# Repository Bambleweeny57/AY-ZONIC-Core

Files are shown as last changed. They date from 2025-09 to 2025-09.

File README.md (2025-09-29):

# 🔊AY-ZONIC-Core

AY-ZONIC-Core is a modular PSG interface designed for the ZX81, supporting both ZON-X and ZON-X-81 compatibility via simplified A4-only decode logic. Rev2.0 introduces gate economy, contributor-friendly schematic clarity, and expansion-ready I/O via AY-3-8912 Port A.

> **This project continues from [JonZON-X](https://github.com/Bambleweeny57/JonZON-X), which was closed at Rev1.4** after timing issues were discovered in demo playback. AY-ZONIC-Core retains the same A4-based decode logic but drops A5 and A6 simplifying the design to single PSG support and saving a gate.

## 🔧 Features

- **Dual-mode decode logic** via DIP switch:
  - **DIP OFF** → A4 pulled high → ZON-X-81 mode
  - **DIP ON** → A4 sourced from ZX81 Expansion Bus → ZON-X mode
- **AY-3-8912 PSG integration** with clean register selection and audio output
- **Series resistors** on data bus for signal protection
- **Pull-ups** from ZX81 Expansion Bus to PSG for stable logic levels
- **Port A expansion header** with +5V and GND for SD card and I/O experimentation
- **/RD decode support** for future peripheral interaction and PSG reads
### DIP Switch Logic — A4 Routing Modes

| DIP Switch | A4 Source | Mode | Description |
|---|---|---|---|
| OFF | Pulled high (via pull-up) | ZON-X-81 | Forces A4 = 1 for simplified decode |
| ON | From ZX81 Expansion Bus  | ZON-X | Enables dynamic A4 control from host |

> This DIP-controlled logic allows seamless switching between ZON-X and ZON-X-81 compatibility without modifying the schematic.
> 
## 🧠 Decode Logic Overview

The schematic uses simplified A4-only address decoding, inherited from JonZON-X Rev1.4. By removing A5 and A6 from the decode path, Rev2.0 drops multi-PSG support in favor of gate economy and contributor clarity.

## 🖼️ Visual Decode Logic

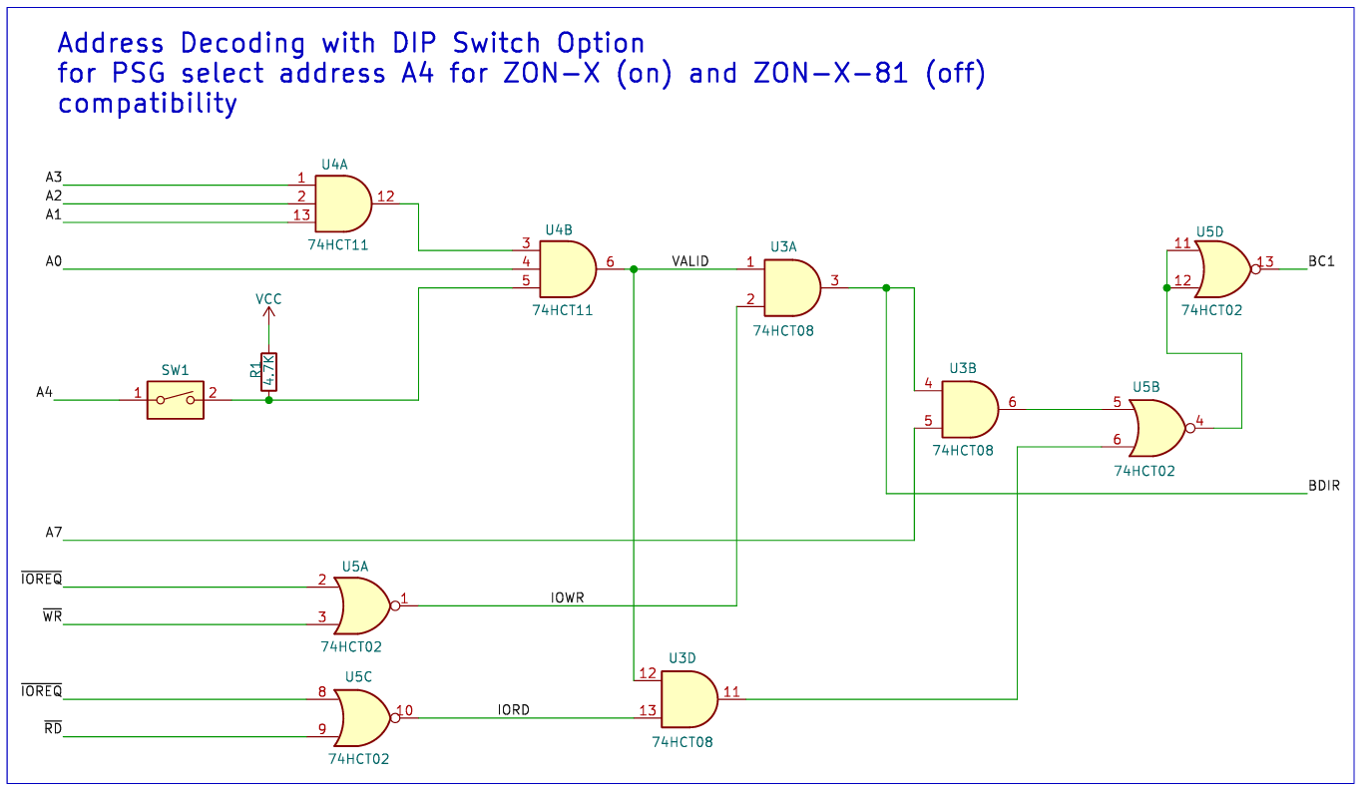
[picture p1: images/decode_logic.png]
AY Control Logic


### Decode Logic Explanation

The PSG is selected when:
- **A4 = 1** (via DIP or bus)
- **A7 = 1** (to avoid bus conflicts)
- **A2 = 1** (used internally by the PSG)
- **/IOREQ = 0** (active I/O cycle)
- **/WR and /RD** combinations determine the operation:
  - `/WR = 1`, `/RD = 1` → Write to register
  - `/WR = 0`, `/RD = 1` → Write to PSG
  - `/WR = 0`, `/RD = 0` → Read from PSG

> `/RD` is now decoded explicitly to support read operations from the PSG and future SD card and I/O interfaces.

### Reference — JonZON-X Rev1.4 Decode Matrix (A5/A6 omitted) for AY-ZONIC-Core

| A0–A4 | A2 | A7 | /IOREQ | /WR | /RD | BDIR | BC1 | Operation |
|---|----|----|---|-----|-----|---|-----|---|
| — | 1  | 1  | 0 | 1 | 1 | 1 | 1 | Write to register |
| — | 1  | 1  | 0 | 0 | 1 | 0 | 1 | Write to PSG |
| — | 1  | 1  | 1 | 0 | 0 | 1 | 0 | Read from PSG |
| — | —  | —  | — | — | — | 0 | 0 | Inactive |

> Rev2.0 removes A5 and A6, streamlining the logic and focusing on single PSG support.

---

## 🔌 Expansion Header (Port A)

Port A of the AY-3-8912 exposes:
- **8 digital I/O lines** (AIO0–AIO7)
- **+5V** and **GND** for powering peripherals

This enables SD card interfacing, experimental I/O modules, and future expansion without modifying the core schematic.

### 🧵 AY-ZONIC-Core I/O Connector Pinout

| Pin | Signal | Description |
|-----|---|---|
| 1 | 5V | Power supply (5 volts) |
| 2 | A0 | Address line 0 |
| 3 | A1 | Address line 1 |
| 4 | A2 | Address line 2 |
| 5 | A3 | Address line 3 |
| 6 | A4 | Address line 4 |
| 7 | A5 | Address line 5 |
| 8 | A6 | Address line 6 |
| 9 | A7 | Address line 7 |
| 10  | GND | Ground |

> This header is ideal for SD card experiments, LED arrays, or future playback logic modules. All signals are directly mapped from the AY-3-8912 Port A.

---

## 🗂️ Repository Structure

- `README.md` — This file
- `src/` — schematic and PCB design files (KiCad v9+)
- `pdf/ay-zonic-core.pdf` — Rev2.x schematic (KiCad source available from /src)
- `images/` — Decode logic diagram and overlays
- `fabfiles/` — Gerber and Exelon Drill fabrication files
- `docs/` — Contributor notes and onboarding diagrams (coming soon)

## 🧭 Contributor Notes

- Keep DIP switch logic annotated in overlays
- Label Port A lines clearly for expansion use
- Use series resistors and pull-ups as shown for safe bus interaction
- Future revisions may include playback logic or UI hooks — modularity is key

## 🛠️ Status

✅ Rev2.0 schematic complete  
🧪 Expansion header tested with SD interface  
📚 Documentation in progress

---

For questions, forks, or onboarding help, feel free to open an issue or start a discussion. Let the AY-3-8912 sing!

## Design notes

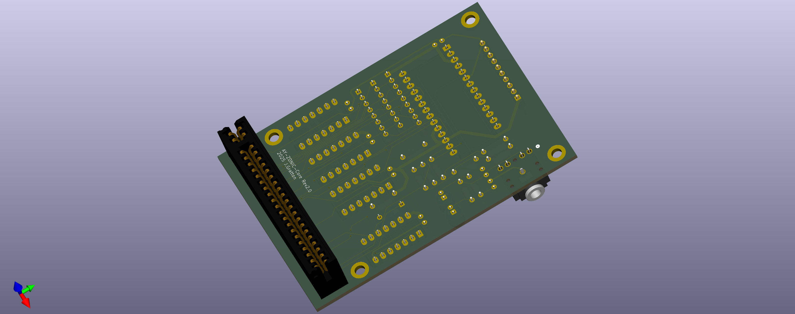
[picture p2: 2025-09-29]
images/3D front.png

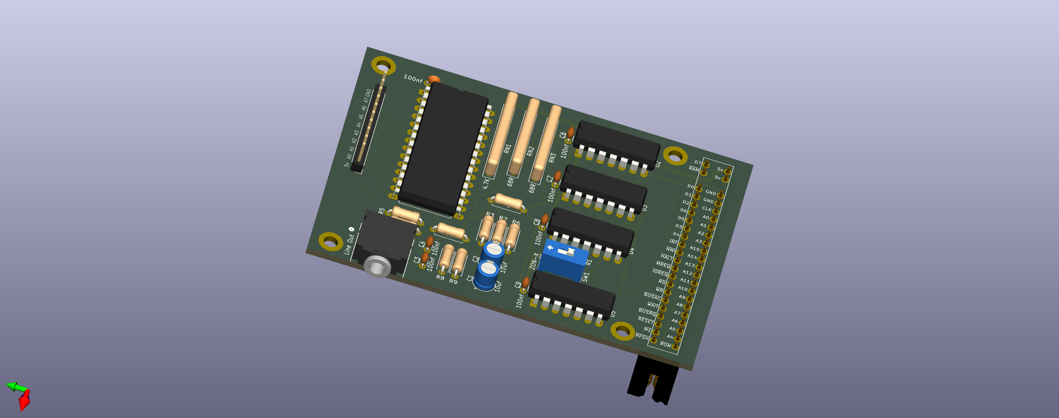
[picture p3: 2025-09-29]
images/3D back.png

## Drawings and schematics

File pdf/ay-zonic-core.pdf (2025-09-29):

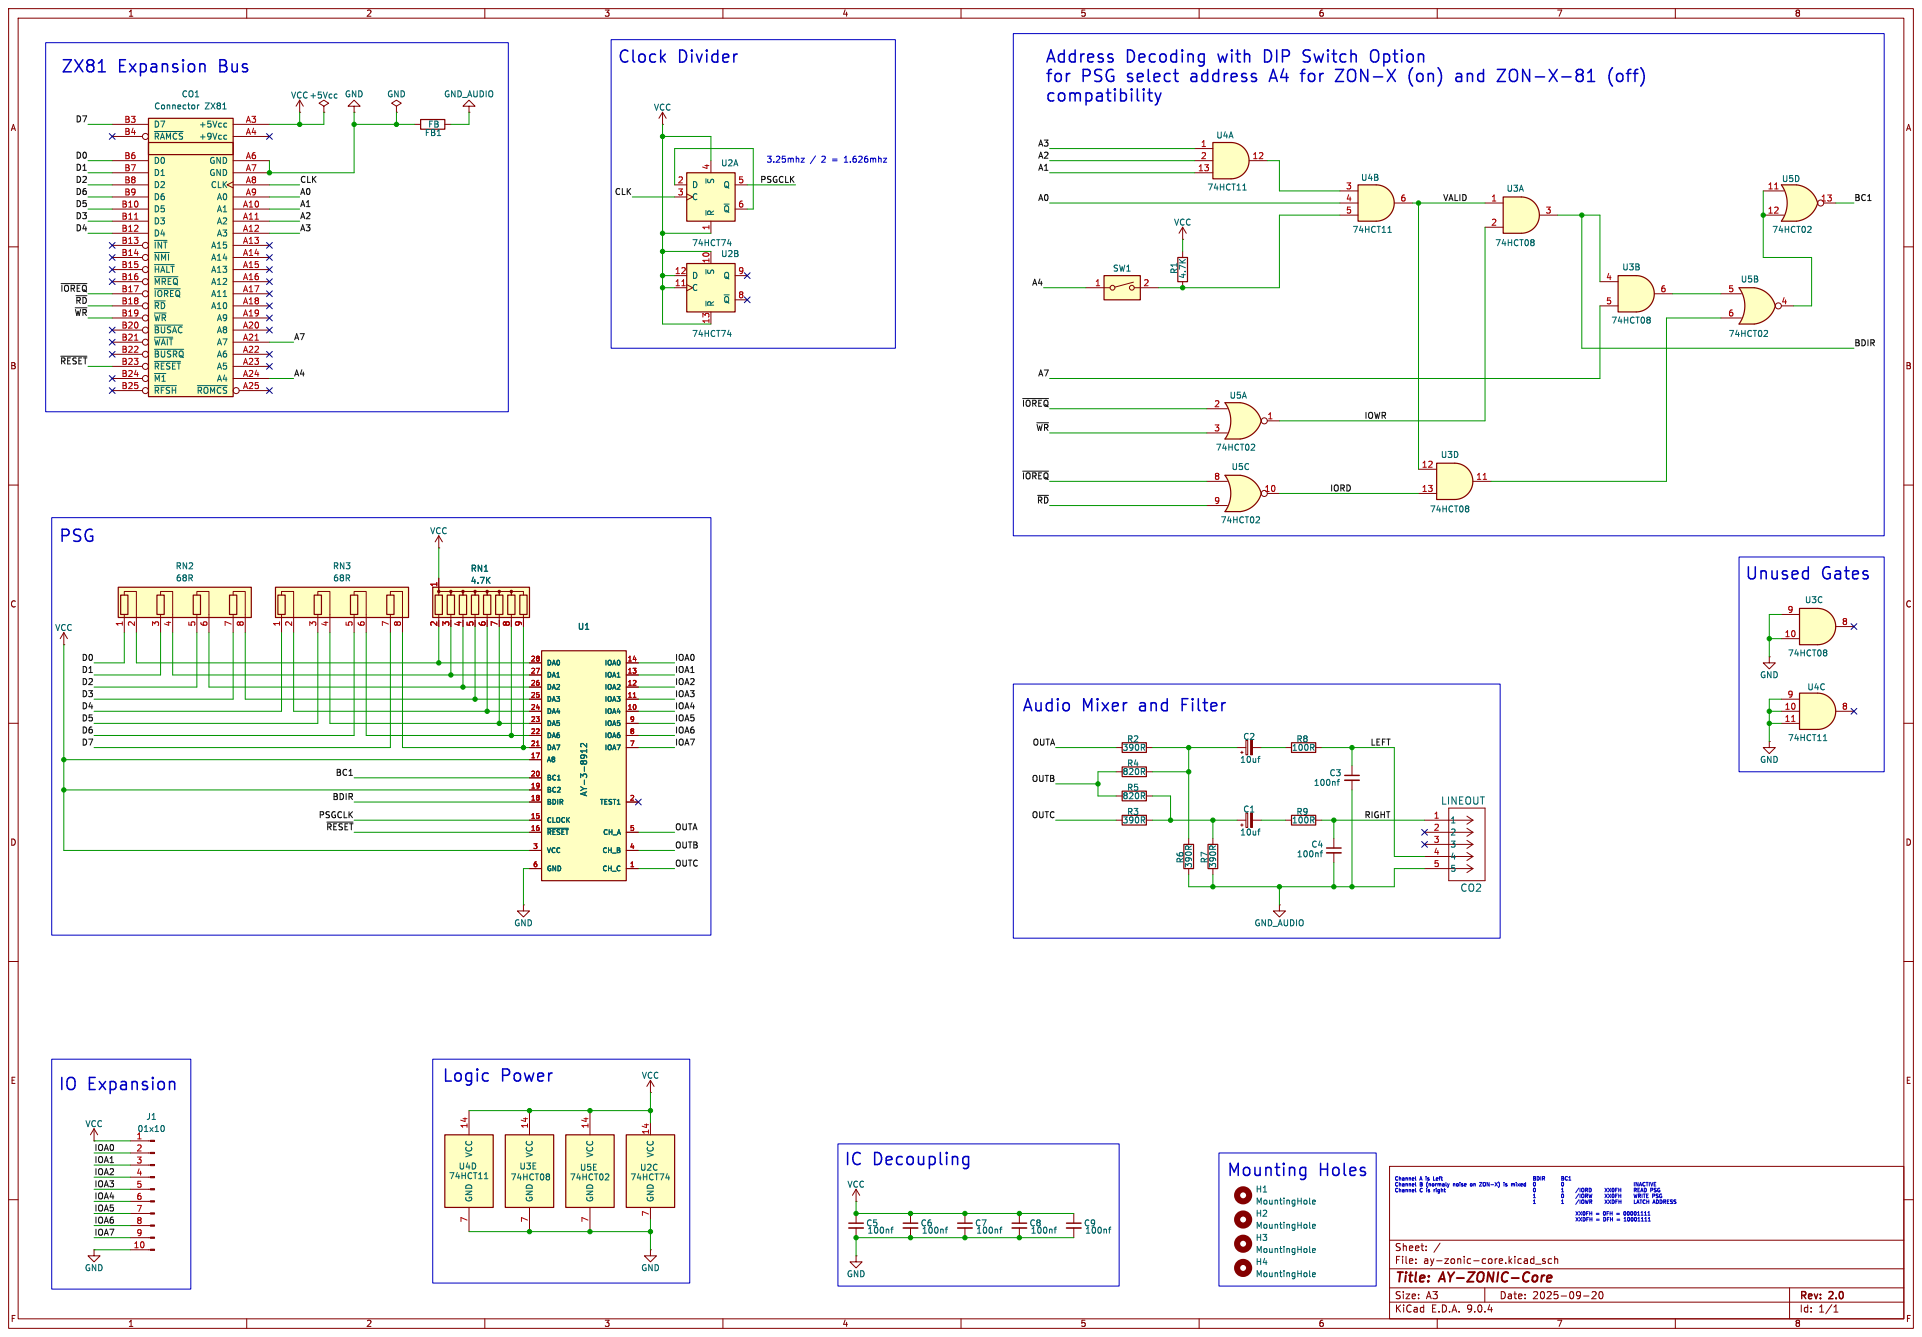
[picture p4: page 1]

Audio Mixer and Filter

File: ay-zonic-core.kicad_sch Sheet: / H3 MountingHole

Id: 1/1 Title: AY-ZONIC-Core

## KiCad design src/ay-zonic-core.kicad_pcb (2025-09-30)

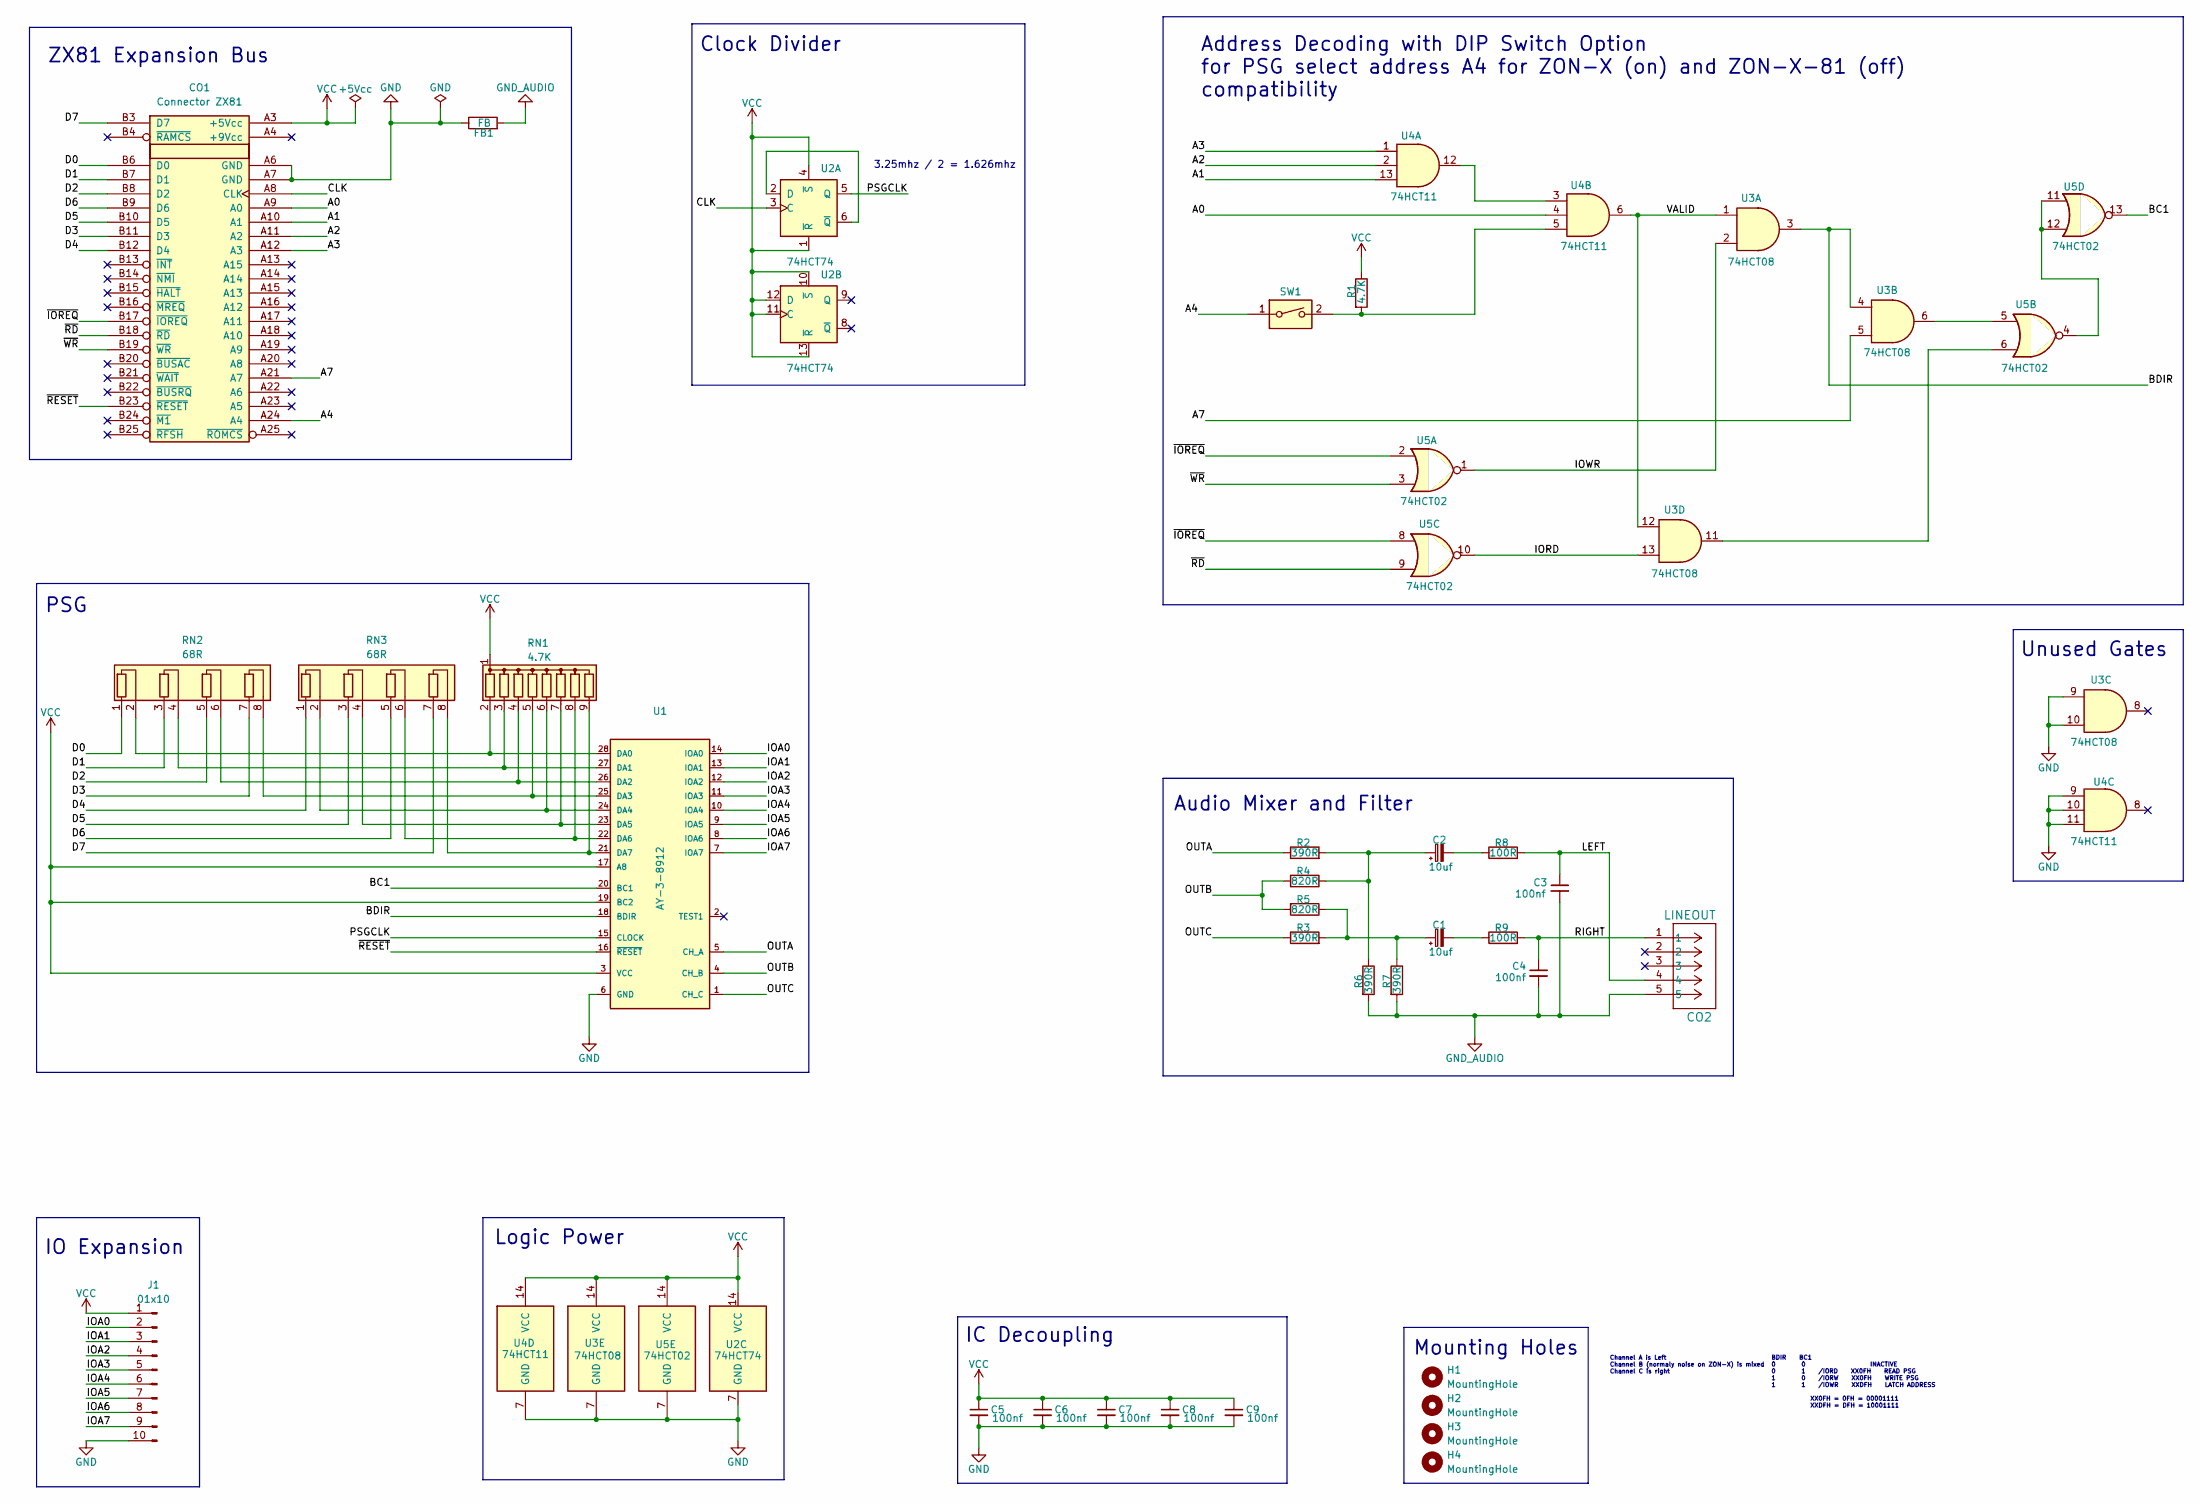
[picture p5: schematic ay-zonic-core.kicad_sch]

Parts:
C1, C2: 10uf; CP_Radial_D5.0mm_P2.00mm
C3, C4, C5, C6, C7, C8, C9: 100nf; C_Disc_D3.0mm_W1.6mm_P2.50mm
CO1: Connector ZX81; ZX81_EdgeConnector
CO2: LINEOUT; CONN5_SPC21348_MTC
FB1: FB; R_Axial_DIN0207_L6.3mm_D2.5mm_P7.62mm_Horizontal
H1, H2, H3, H4: MountingHole; MountingHole_3.2mm_M3_DIN965_Pad
J1: 01x10; PinHeader_1x10_P2.54mm_Vertical
R1: 4.7K; R_Axial_DIN0207_L6.3mm_D2.5mm_P7.62mm_Horizontal
R2, R3, R6, R7: 390R; R_Axial_DIN0207_L6.3mm_D2.5mm_P7.62mm_Horizontal
R4, R5: 820R; R_Axial_DIN0207_L6.3mm_D2.5mm_P7.62mm_Horizontal
R8, R9: 100R; R_Axial_DIN0207_L6.3mm_D2.5mm_P7.62mm_Horizontal
RN1: 4.7K; R_Array_SIP9
RN2, RN3: 68R; R_Array_SIP8
SW1: SW_DIP_x01; SW_DIP_SPSTx01_Slide_9.78x4.72mm_W7.62mm_P2.54mm
U1: AY-3-8912; DIP-28_W15.24mm_LongPads
U2: 74HCT74; DIP-14_W7.62mm_LongPads
U3: 74HCT08; DIP-14_W7.62mm_LongPads
U4: 74HCT11; DIP-14_W7.62mm_LongPads
U5: 74HCT02; DIP-14_W7.62mm_LongPads

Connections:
/A0: CO1.A9 (A0), U4.4
/A1: CO1.A10 (A1), U4.13
/A2: CO1.A11 (A2), U4.2
/A3: CO1.A12 (A3), U4.1
/A4: CO1.A24 (A4), SW1.1
/A7: CO1.A21 (A7), U3.5
/BC1: U1.20 (BC1), U5.13
/BDIR: U1.18 (BDIR), U3.3, U3.4
/CLK: CO1.A8 (CLK), U2.3 (C)
/D0: CO1.B6 (D0), RN2.1 (R1.1)
/D1: CO1.B7 (D1), RN2.3 (R2.1)
/D2: CO1.B8 (D2), RN2.5 (R3.1)
/D3: CO1.B11 (D3), RN2.7 (R4.1)
/D4: CO1.B12 (D4), RN3.1 (R1.1)
/D5: CO1.B10 (D5), RN3.3 (R2.1)
/D6: CO1.B9 (D6), RN3.5 (R3.1)
/D7: CO1.B3 (D7), RN3.7 (R4.1)
/IOA0: J1.2, U1.14 (IOA0); also elsewhere on the board
/IOA1: J1.3, U1.13 (IOA1); also elsewhere on the board
/IOA2: J1.4, U1.12 (IOA2); also elsewhere on the board
/IOA3: J1.5, U1.11 (IOA3); also elsewhere on the board
/IOA4: J1.6, U1.10 (IOA4); also elsewhere on the board
/IOA5: J1.7, U1.9 (IOA5); also elsewhere on the board
/IOA6: J1.8, U1.8 (IOA6); also elsewhere on the board
/IOA7: J1.9, U1.7 (IOA7); also elsewhere on the board
/IORD: U3.13, U5.10
/IOWR: U3.2, U5.1
/LEFT: C3.1, CO2.4, R8.2; also elsewhere on the board
/OUTA: R2.1, U1.5 (CH_A)
/OUTB: R4.2, R5.2, U1.4 (CH_B)
/OUTC: R3.1, U1.1 (CH_C)
/PSGCLK: U1.15 (CLOCK), U2.5 (Q)
/RIGHT: C4.1, CO2.1, R9.2; also elsewhere on the board
/VALID: U3.1, U3.12, U4.6
/~IOREQ: CO1.B17 (~IOREQ), U5.2, U5.8
/~RD: CO1.B18 (~RD), U5.9
/~RESET: CO1.B23 (~RESET), U1.16 (~RESET)
/~WR: CO1.B19 (~WR), U5.3
GND: C5.2, C6.2, C7.2, C8.2, C9.2, CO1.A6 (GND), CO1.A7 (GND), FB1.1, J1.10, U1.6 (GND), U2.7 (GND), U3.7 (GND), U3.9, U3.10, U4.7 (GND), U4.9, U4.10, U4.11, U5.7 (GND); also elsewhere on the board
GND_AUDIO: C3.2, C4.2, CO2.5, FB1.2, R6.2, R7.2; also elsewhere on the board
unnamed: C1.1, R3.2, R5.1, R7.1
unnamed: C1.2, R9.1
unnamed: C2.1, R2.2, R4.1, R6.1
unnamed: C2.2, R8.1
unnamed: R1.2, SW1.2, U4.5
unnamed: RN1.2 (R1), RN2.2 (R1.2), U1.28 (DA0)
unnamed: RN1.3 (R2), RN2.4 (R2.2), U1.27 (DA1)
unnamed: RN1.4 (R3), RN2.6 (R3.2), U1.26 (DA2)
unnamed: RN1.5 (R4), RN2.8 (R4.2), U1.25 (DA3)
unnamed: RN1.6 (R5), RN3.2 (R1.2), U1.24 (DA4)
unnamed: RN1.7 (R6), RN3.4 (R2.2), U1.23 (DA5)
unnamed: RN1.8 (R7), RN3.6 (R3.2), U1.22 (DA6)
unnamed: RN1.9 (R8), RN3.8 (R4.2), U1.21 (DA7)
unnamed: U2.2 (D), U2.6 (~Q)
unnamed: U3.6, U5.5
unnamed: U3.11, U5.6
unnamed: U4.3, U4.12
unnamed: U5.4, U5.11, U5.12
VCC: C5.1, C6.1, C7.1, C8.1, C9.1, CO1.A3 (+5Vcc), J1.1, R1.1, RN1.1 (common), U1.3 (VCC), U1.17 (A8), U1.19 (BC2), U2.1 (~R), U2.4 (~S), U2.10 (~S), U2.11 (C), U2.12 (D), U2.13 (~R), U2.14 (VCC), U3.14 (VCC), U4.14 (VCC), U5.14 (VCC); also elsewhere on the board

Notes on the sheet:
IO Expansion
Audio Mixer and Filter
ZX81 Expansion Bus
3.25mhz / 2 = 1.626mhz
Unused Gates
Address Decoding with DIP Switch Option for PSG select address A4 for ZON-X (on) and ZON-X-81 (off) compatibility
IC Decoupling
Mounting Holes
Logic Power
Channel A is Left Channel B (normaly noise on ZON-X) is mixed Channel C is right
PSG
BDIR BC1 0 0 INACTIVE 0 1 /IORD XX0FH READ PSG 1 0 /IORW XX0FH WRITE PSG 1 1 /IOWR XXDFH LATCH ADDRESS XX0FH = 0FH = 00001111 XXDFH = DFH = 10001111
Clock Divider

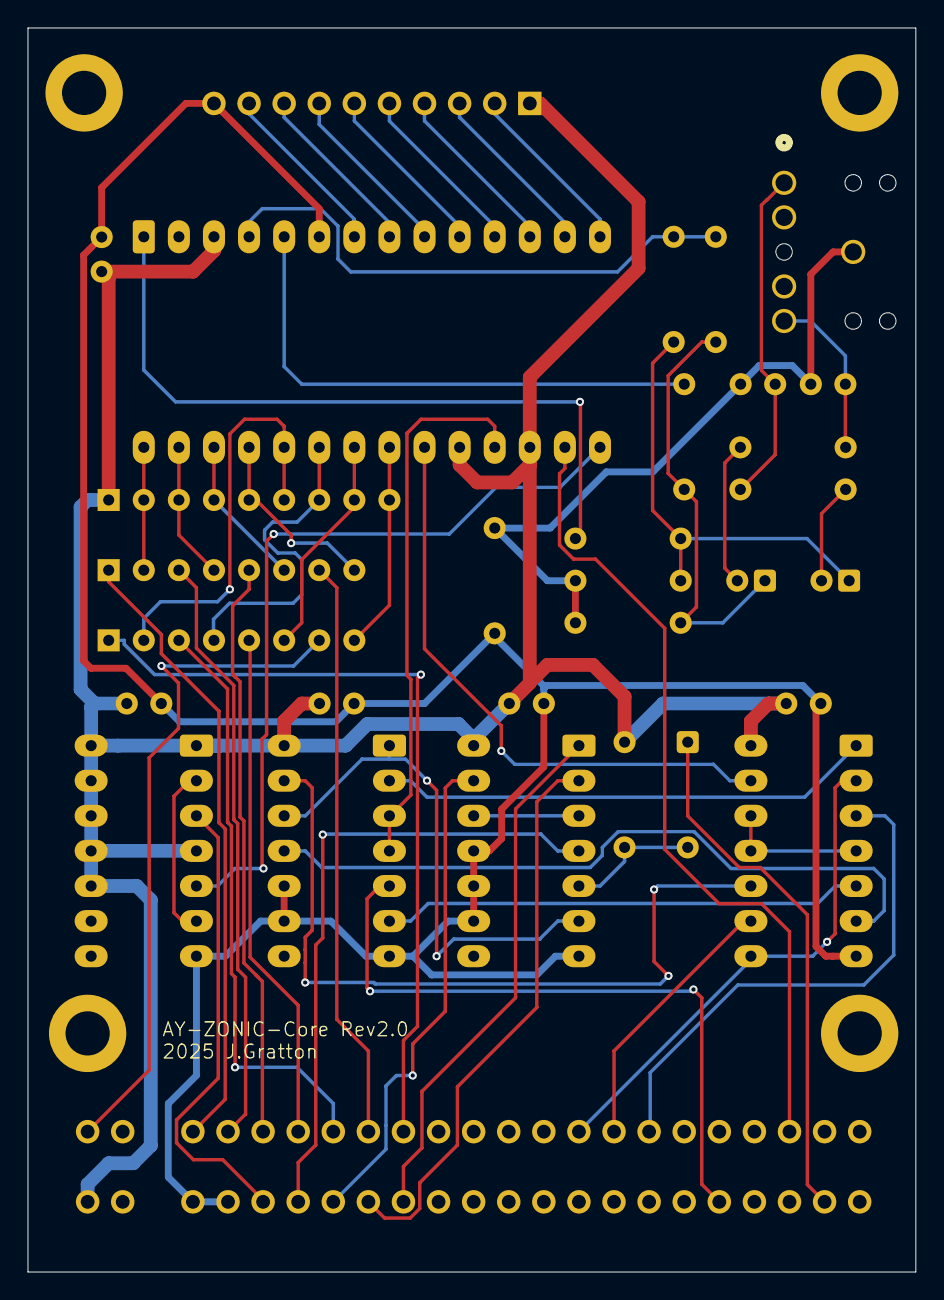
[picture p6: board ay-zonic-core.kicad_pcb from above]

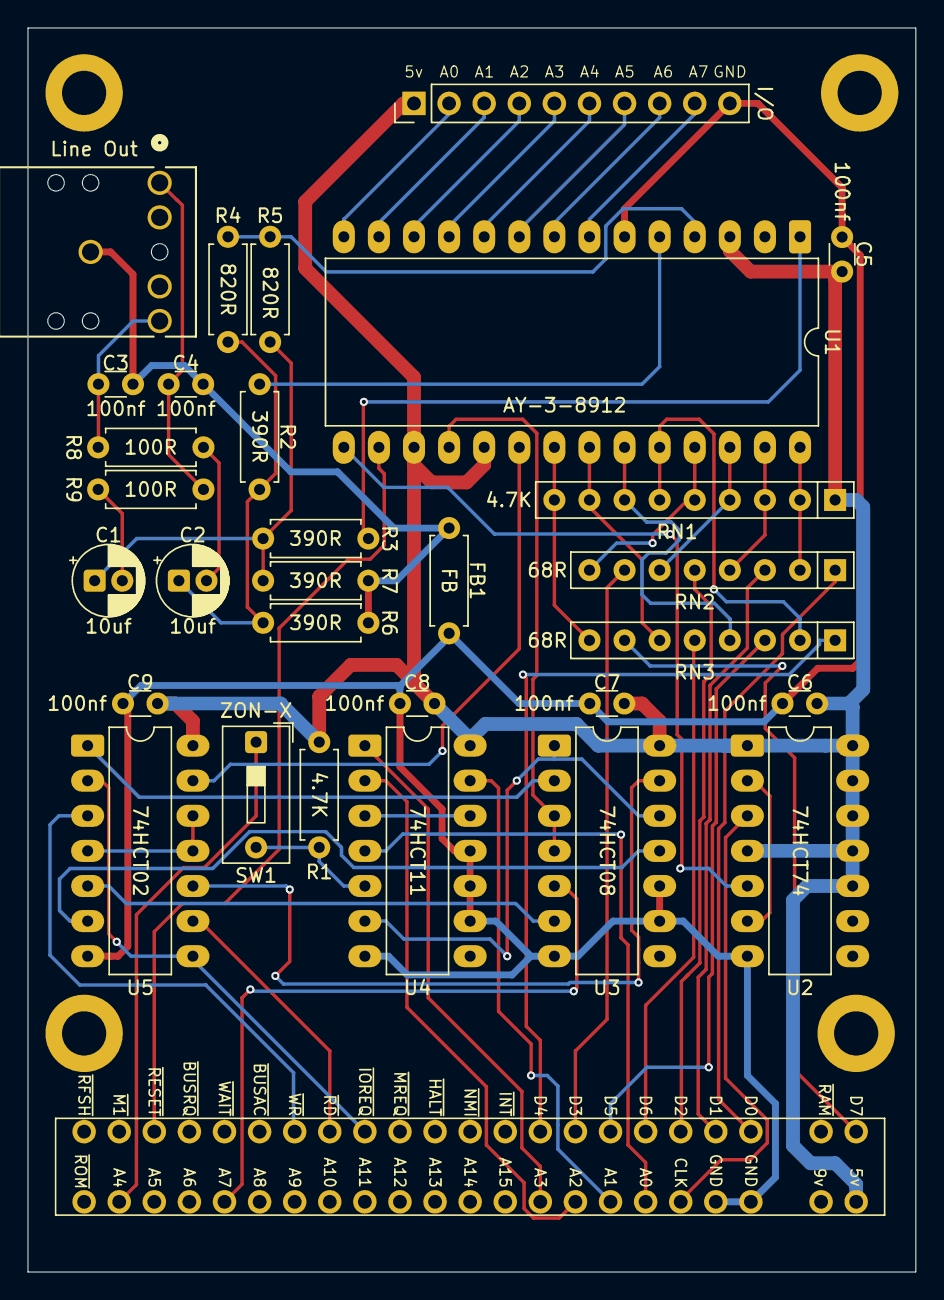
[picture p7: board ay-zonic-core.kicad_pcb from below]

Board: 2 copper layers, 64.3 x 90.0 mm, 35 parts (30 on the bottom side), 59 nets.

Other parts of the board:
I/O: 01x10; PinHeader_1x10_P2.54mm_Vertical
Line Out: LINEOUT; CONN5_SPC21348_MTC

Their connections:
/IOA0: I/O.2; also elsewhere on the board
/IOA1: I/O.3; also elsewhere on the board
/IOA2: I/O.4; also elsewhere on the board
/IOA3: I/O.5; also elsewhere on the board
/IOA4: I/O.6; also elsewhere on the board
/IOA5: I/O.7; also elsewhere on the board
/IOA6: I/O.8; also elsewhere on the board
/IOA7: I/O.9; also elsewhere on the board
/LEFT: Line Out.4; also elsewhere on the board
/RIGHT: Line Out.1; also elsewhere on the board
GND: I/O.10; also elsewhere on the board
GND_AUDIO: Line Out.5; also elsewhere on the board
VCC: I/O.1; also elsewhere on the board

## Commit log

2025-09-20 Initial push
    [ay-zonic-core.kicad_pcb, ay-zonic-core.kicad_sch]
2025-09-21 Added schematic symbols and footprints
    [SPC21348.stp]
2025-09-24 added 3d model for edge connector and footprints plus added schematic to pcb.
    [SPC21348.stp, ay-zonic-core.kicad_pcb, ay-zonic-core.kicad_sch]
2025-09-24 new back 3D image
    [ay-zonic-core.kicad_pcb]
2025-09-24 new pdf of the schematic
2025-09-25 added labels to IO connector
    [ay-zonic-core.kicad_pcb]
2025-09-25 routed and new images
    [ay-zonic-core.kicad_pcb]
2025-09-25 Added fab files
    [ay-zonic-core-B_Cu.gbr, ay-zonic-core-B_Mask.gbr, ay-zonic-core-B_Paste.gbr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]
2025-09-25 saved pcb
2025-09-28 added mounting holes and started routing.
    [ay-zonic-core.kicad_pcb, ay-zonic-core.kicad_sch]
2025-09-28 updated routing
    [ay-zonic-core-B_Cu.gbr, ay-zonic-core-B_Mask.gbr, ay-zonic-core-B_Paste.gbr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]
2025-09-29 final route rev 2.0
    [ay-zonic-core-B_Cu.gbr, ay-zonic-core-B_Mask.gbr, ay-zonic-core-B_Paste.gbr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]
2025-09-30 rerouted a few things to make them better
    [ay-zonic-core-B_Cu.gbr, ay-zonic-core-B_Mask.gbr, ay-zonic-core-B_Paste.gbr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]
